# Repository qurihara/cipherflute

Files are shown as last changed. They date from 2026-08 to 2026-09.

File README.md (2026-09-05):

# CipherFlute



**3Dプリントした笛の音の高さに秘密を書き込み、吹いて読み出す。**

笛は電源も電子部品も持たない。家庭用の3Dプリンタで作れて、日用品の内部空洞として
存在できる。読み出しに特別な装置は不要である。

このリポジトリは、CipherFluteプロジェクトの成果物である。
開発は別のリポジトリで行っており、ここへはスクリプトで切り出している。

| | | |
|---|---|---|
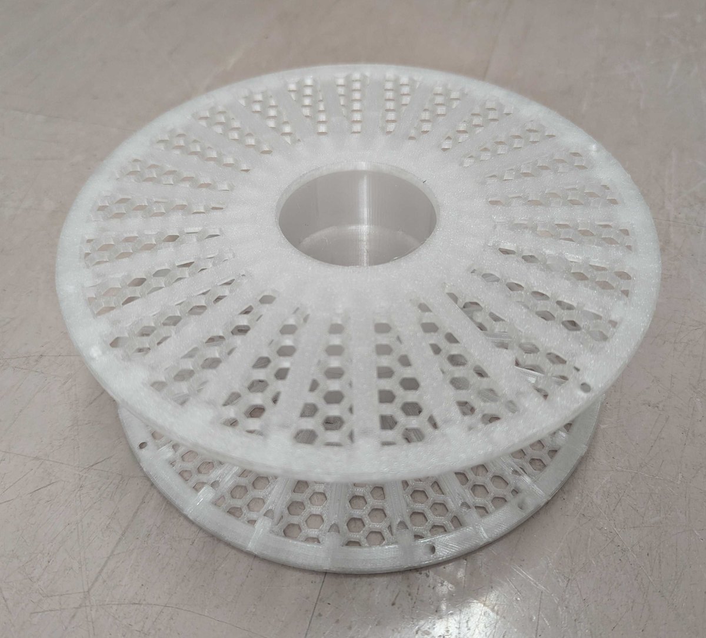
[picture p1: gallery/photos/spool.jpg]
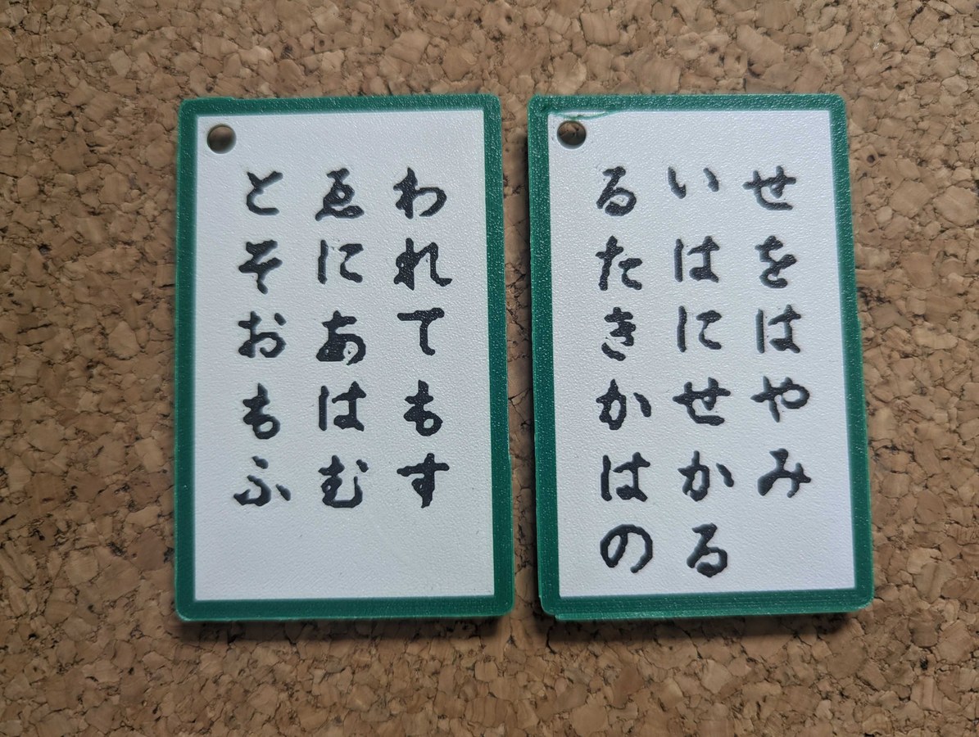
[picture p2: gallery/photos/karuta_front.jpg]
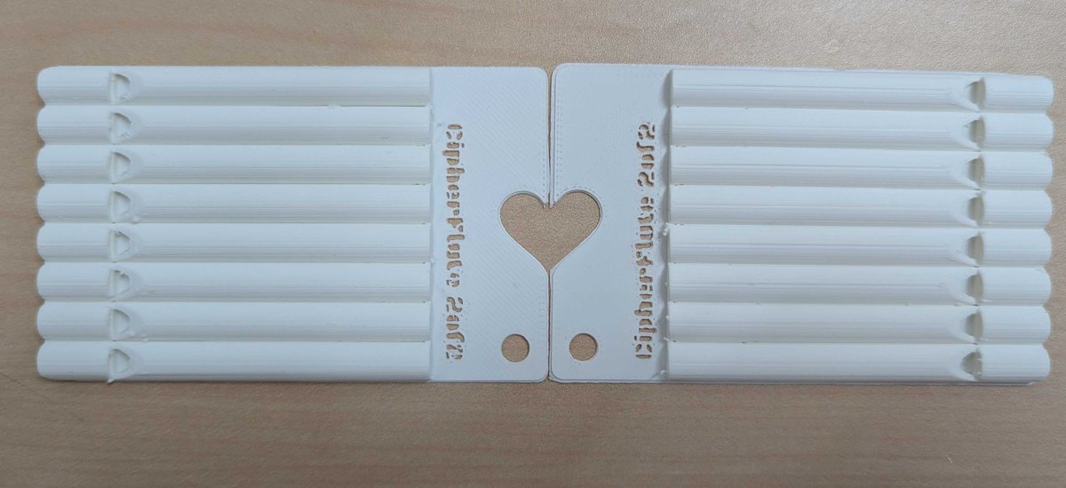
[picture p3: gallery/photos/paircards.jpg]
|  |  |  |
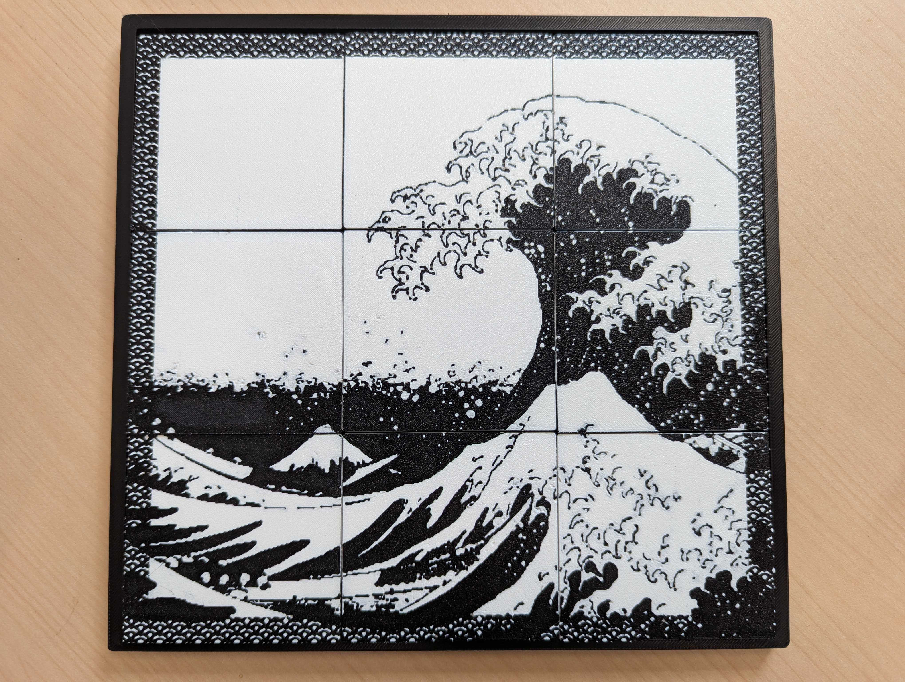
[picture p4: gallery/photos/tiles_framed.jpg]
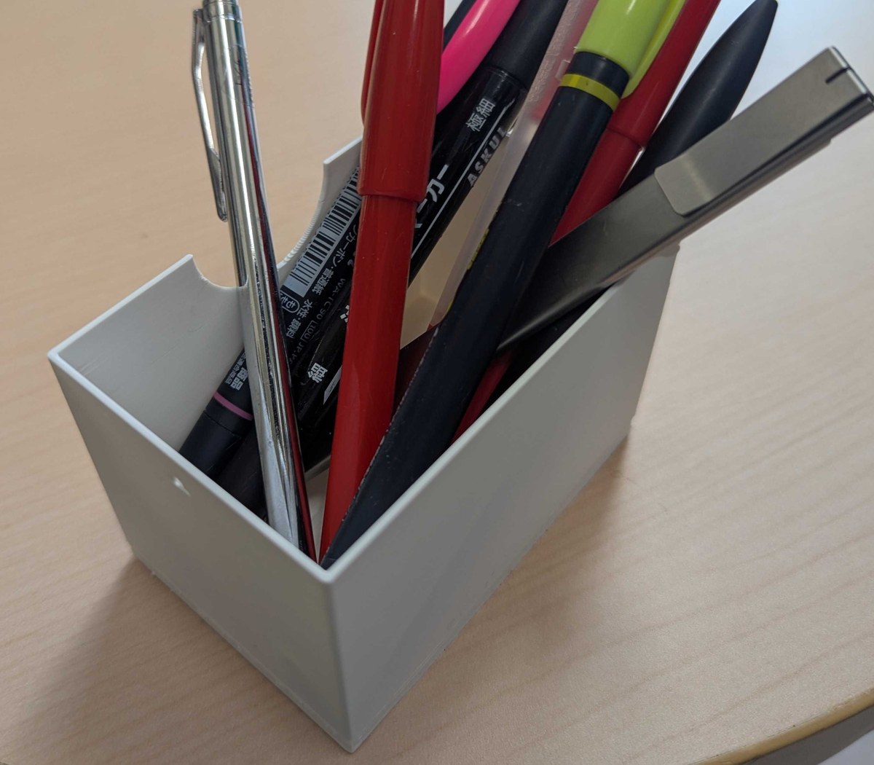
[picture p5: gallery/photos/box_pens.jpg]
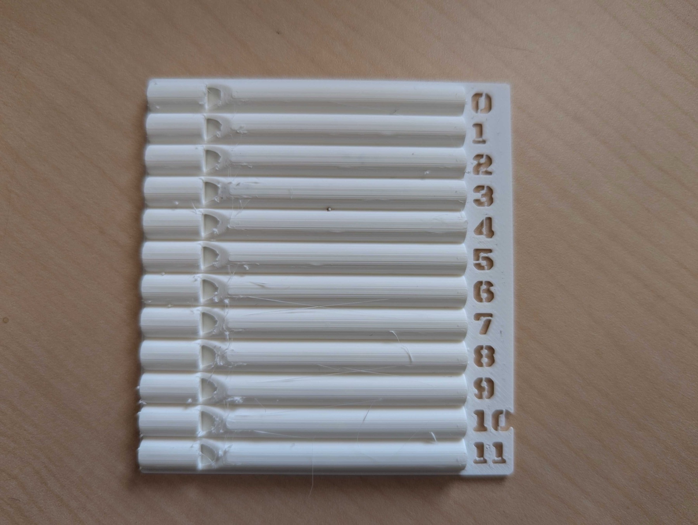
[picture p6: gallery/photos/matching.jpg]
|  |  |  |

写真の作例はどれも実機で復号まで通っている。詳しくは [`gallery/`](gallery/) を見ること。

## 5分で試す

1. `flutes/uniform/` の笛を何本か印刷する（0.20mm・サポートなし・ブリム8mm前後）
2. `decoder/index.html` をブラウザで開く
3. 「開始」を押して、印刷した笛を順に吹く

音の高さが読み取れれば、その並びが記号になる。何を書き込むかは、どの笛を
どの順で並べるかで決める。

## 中身

| 場所 | 何が入っているか |
|---|---|
| `flutes/` | 統一管長の笛12音ぶんのSTLと較正データ |
| `codec/` | 符号の参照実装（Python）と**試験ベクタ**と仕様書、**紙の上で復号するための早見表** |
| `decoder/` | ブラウザだけで動く復号器。検査94件つき |
| `embed/` | 日用品へ埋め込む道具と、2つの検査、**手順書2種** |
| `wallet/` | 笛から鍵と口座を導き、送金までできるページ（**テストネットの実験**） |
| `gallery/` | 作例の写真と造形データ（かるた札ペアキーホルダー・ペアカード・カード・箱・画像タイル・照合笛） |

## 笛の素材（`flutes/`）

スロット（音の高さの置き場）は **G#6 から G7 までの12個**、半音刻みである。半音刻みにしてあるので、
平均律の鍵盤楽器がそのまま対照表になる。

**外形はすべて同じ 65.97 × 7 × 4mm で、中の空洞の長さだけが違う。**
見ただけでは、どの笛がどの音かは分からない。

管の長さと音の高さは `calibration.json` の式で対応づける。

```
freq_hz = A / (bore_mm - e)      A = 87985.1, e = -10.010
```

**この係数は手元の環境で当てはめたものである。** プリンタや材料が違えばずれるので、
較正コームを刷って測り直すこと。当てはめには設計値ではなく、造形データから実測した
空洞の長さを用いている。

印刷して**鳴る向き**には範囲がある。横置きで、窓の向きが −135度から +135度の間なら
鳴る（360度のうち270度）。`embed/orient_check.py` で確認できる。

## 符号（`codec/`）

**同じ仕様を2つの言語で書いてある。** `codec/cipher_codec.py`（Python）と
`decoder/cipher_codec.js`（JavaScript）である。両者が一致していることを
`test_vectors.json` の12件で突き合わせている。

**別の言語で実装するときは、この試験ベクタで自分の実装を確かめられる。**

```bash
node decoder/cipher_codec.test.js     # ALL PASS (12 vectors)
```

符号の詳しい仕様は [`codec/SPEC.md`](codec/SPEC.md) にある。実装に足る細かさで記述してある。

**紙と鉛筆だけで誤り訂正まで行うための早見表**を [`codec/manual_decode_card.md`](codec/manual_decode_card.md)
に置いた。位数11の有限体では2が原始根なので、10項のべき乗表と10項の対数表があれば、
掛け算と割り算は足し算と引き算になる。手順が実装と食い違っていないかは
`codec/verify_manual_decode.py` で確認できる。

## 復号器（`decoder/`）

ブラウザだけで動く。その場で吹いても、録音した音声を入力しても復号できる。

読み取りの入口は4つある。

- 1本ずつ確定する
- 続けて吹いて、無音で自動送りする
- **一定のテンポで吹いて、あとからまとめて読む**（おすすめ）
- 録音ファイルを読み込む

音の高さは**笛の音域の中でいちばん強い山を追う**方式で検出する（`fft_peak.js`）。
自己相関にもとづく方式は、符号の最低音 G#6 に無関係な値を返すことがあり、使えない。

鳴らない笛があっても、拍を1つ空けて吹き続ければ、あとから拍を手がかりに
「飛ばし」を入れる。誤り訂正の消失として扱われるので、検査用の笛が足りていれば復元できる。

```bash
cd decoder && for t in fft_peak silence_segmenter tempo_filter cipher_codec; do
  node $t.test.js; done
```

## 日用品への埋め込み（`embed/`）

任意の3Dモデルに笛を配置して、印刷できる形にする。手順書は2つある。
人が読むなら [`embed/HOWTO.md`](embed/HOWTO.md)、
**大規模言語モデルの助手に読ませるなら** [`embed/flute-embed.md`](embed/flute-embed.md) である。
判断を伴う部分は手順書の側にあるので、埋め込みの再現には手順書とプログラムの両方を必要とする。

**核心は、笛の外形の凸包でホスト側にポケットを彫り抜いてから笛を戻すことである。**
これを略すと、ホストの材料が笛の空洞を埋めて鳴らなくなる。

作ったものが鳴るかどうかは、印刷する前に2つの検査で確認できる。

- `orient_check.py` … 印刷の向きが鳴る範囲に入っているか
- `check_cavity.py` … スライスした後の実際の経路を読み、空洞に材料が置かれていないか

**鳴らない物を作ってしまう失敗は、この2つでほとんど防げる。**

## 暗号笛ウォレット（`wallet/`）

笛を吹くと、その場で秘密鍵が組み立てられ、ブロックチェーン上の口座が現れる。
残高を見て、送金までできる。財布アプリは介さず、**笛から導いた鍵が直接署名する**。
鍵はどこにも保存せず、ページを閉じれば消える。

**★本物の資産には使わないこと。★** ネットワークはテストネット（Polygon Amoy）である。
カード1枚の秘密は20.8bitしかないので、**そこから導いた口座のアドレスが公開の台帳に
現れた時点で、総当たりで秘密鍵に到達される**。遅い鍵導出（PBKDF2 60万回）を通しても、
それは1候補あたりの費用を上げるだけで、足りない情報量を補うものではない。

対処は2つある。**128bitの秘密（スプール2枚）を使う**か、**笛の秘密に持ち主が覚えている
合言葉を混ぜて2要素にする**かである。後者はページで試せる（合言葉の既定は `demo`）。
詳しい検討は [`wallet/DESIGN.md`](wallet/DESIGN.md) にある。

```bash
node wallet/flute_key.test.js     # 鍵導出（9件）
node wallet/tx.test.js            # 送金（29件）
```

## 印刷の設定について

**同梱していない。** 機種と個体と材料に強く依存し、そのまま使うとかえって失敗するためである。
条件だけ記す。

- 層の厚さ 0.20mm（初層も同じ）
- サポート なし（笛は横置きで、ボアにサポートが入らない向きに置く）
- ブリム 外周のみ 8mm 前後（薄く面積の大きい板では反り止めに効く）
- 材料 PLA。PETGでも鳴るが、薄い壁では失敗しやすい

## 何が守られ、何が守られないか

**方式そのものは公開であり、秘密は値だけである。**

- 物体の層にも音の層にも、暗号学的な秘匿の力は**無い**
- 音は公開のチャネルである。吹いているところを録音されれば秘密は漏れる
- 形状が秘密である。3Dスキャンや写真測量で読まれうる
- 秘匿が必要なら**秘密分散**を使う。`codec/threshold.py` にShamirの実装がある

## ライセンス

- コード … MIT（[LICENSE](LICENSE)）
- 3Dデータ・写真 … CC BY 4.0（[LICENSE-assets](LICENSE-assets)）
- 第三者の権利については [NOTICE.md](NOTICE.md) を読むこと

## 引用

```bibtex
@misc{cipherflute,
  author       = {栗原 一貴},
  title        = {CipherFlute},
  year         = {2026},
  howpublished = {\url{https://github.com/qurihara/cipherflute}}
}
```

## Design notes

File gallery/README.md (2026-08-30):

# 作例

実機で復号まで通ったものである。造形データは、どれもデモ用の秘密を記録してある。

| 作例 | 秘密の分け方 | 笛の本数 | 造形データ |
|---|---|---|---|
| かるた札ペアキーホルダー2枚 | 2-of-2 | 8本ずつ | `models/karuta_2of2.3mf` |
| ハートを抜いたペアカード | 2-of-2 | 8本ずつ | `models/paircards_2of2.3mf` |
| カード1枚 | 単体、または2-of-3の断片 | 8本 | `models/card.3mf` |
| 箱 | 2-of-3の断片 | 8本 | `models/box.3mf` |
| 画像タイル9枚 | 2-of-9 | 9本ずつ | 額縁と脚のみ同梱 |
| 照合笛 | なし（読み出しの道具） | 12本 | `models/matching.3mf` |

## かるた札ペアキーホルダー2枚

百人一首の1首を上の句と下の句に分けて刷り、それぞれの裏に笛を8本ずつ載せた。
崇徳院の「瀬をはやみ岩にせかるる滝川のわれても末に逢はむとぞ思ふ」を選んである。

**分かれてもいずれまた出会うという歌の内容が、2-of-2の秘密分散そのものになっている。**
2枚をそろえる理由が物の側に書いてあり、歌の完成と秘密の復元が一致する。

- クレジットカードと同じ寸法を縦長にとり、厚さ4.8mm。絵柄0.4mm＋素地0.4mm＋笛4mm
- 白い地に黒い字を刷り、縁を緑で囲んだ3色刷りである
- 絵柄は0.4mmの格子に量子化されるので、1文字を29画素にとって毛筆の入りと払いを残した
- **2枚の札は先頭の2本が同じ音である。**基準笛と、差分の写像で決まる次の1本が
  両方に共通するためで、**吹く向きを間違えていないかは、1本目が基準笛の高さになるかで分かる**

| 写真 | 何が写っているか |
|---|---|
| `photos/karuta_front.jpg` | 2枚を並べたところ。右が上の句、左が下の句 |
| `photos/karuta_back.jpg` | 上の句の札を裏返したところ。笛8本が並ぶ |

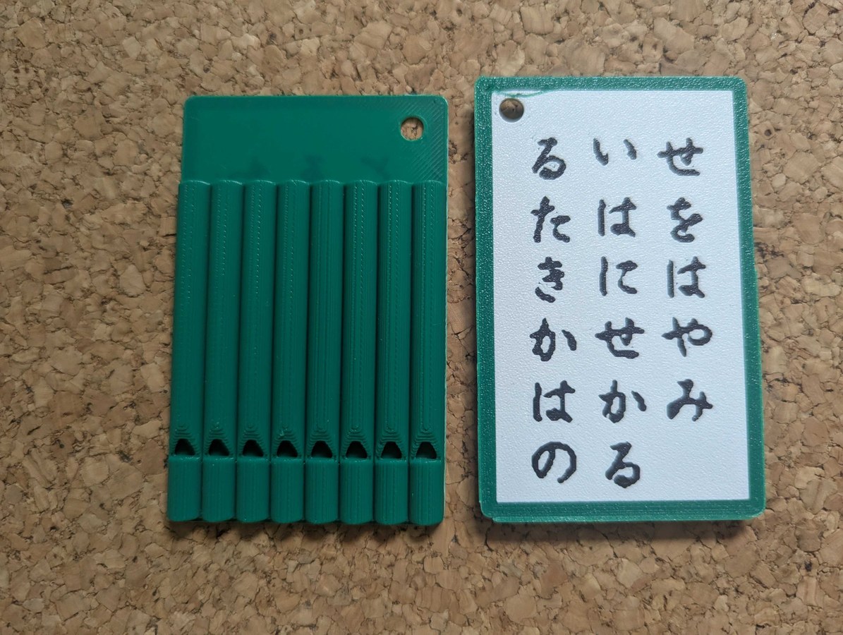
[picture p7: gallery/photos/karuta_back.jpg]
 

## ハートを抜いたペアカード

同じ作りのカードを2枚、余白どうしを向かい合わせに並べ、その境界にハートを抜いた。
1枚では半分のハートにしかならず、**2枚をそろえて初めてハートが現れる。**

秘密は2-of-2で分け、片方に一方の値を、もう片方に秘密からその値を引いた値を割り当てる。
方式としては、片方だけでは一様な乱数にしか見えない。
**ただしこのリポジトリの実装は、再現できるように分け方の値を固定してある。**
実際に配る物を作るときは、組ごとに種を変えること。

合成した秘密を鍵として遷移先のURLを暗号化しておくと、2枚がそろったときにだけそのページが開く。
この秘匿の強度は、載っている情報量（20.8bit）のままである。

| 写真 | 何が写っているか |
|---|---|
| `photos/paircards.jpg` | 2枚をそろえてハートが現れたところ |



## カード1枚

クレジットカード大の板（85.6 × 54 × 4mm）に笛8本を融合したものである。
先頭の1本を基準笛にあて、残り7本にデータとパリティの記号を載せる。**20.8bitを記録する。**

財布に入れて持ち歩ける薄さで、見た目は音楽用のカードと同じである。

| 写真 | 何が写っているか |
|---|---|
| `photos/card.jpg` | カード1枚。右上の印が吹き始めである |
| `photos/card_2of3.jpg` | 2-of-3の断片を担当するカード |

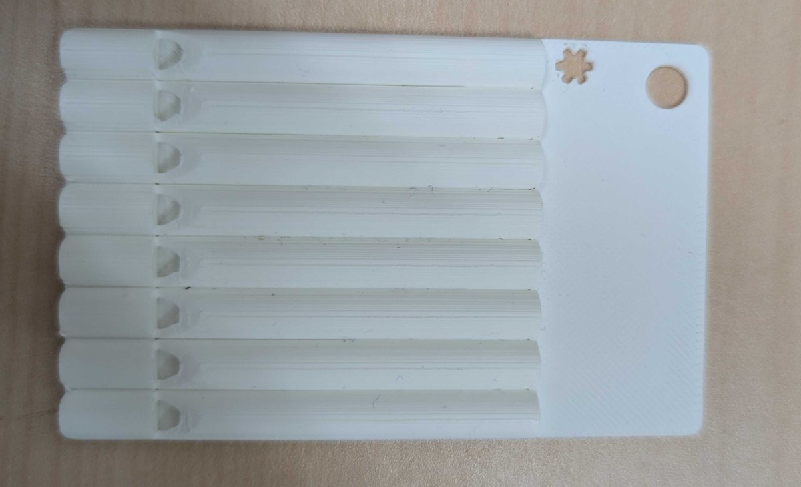
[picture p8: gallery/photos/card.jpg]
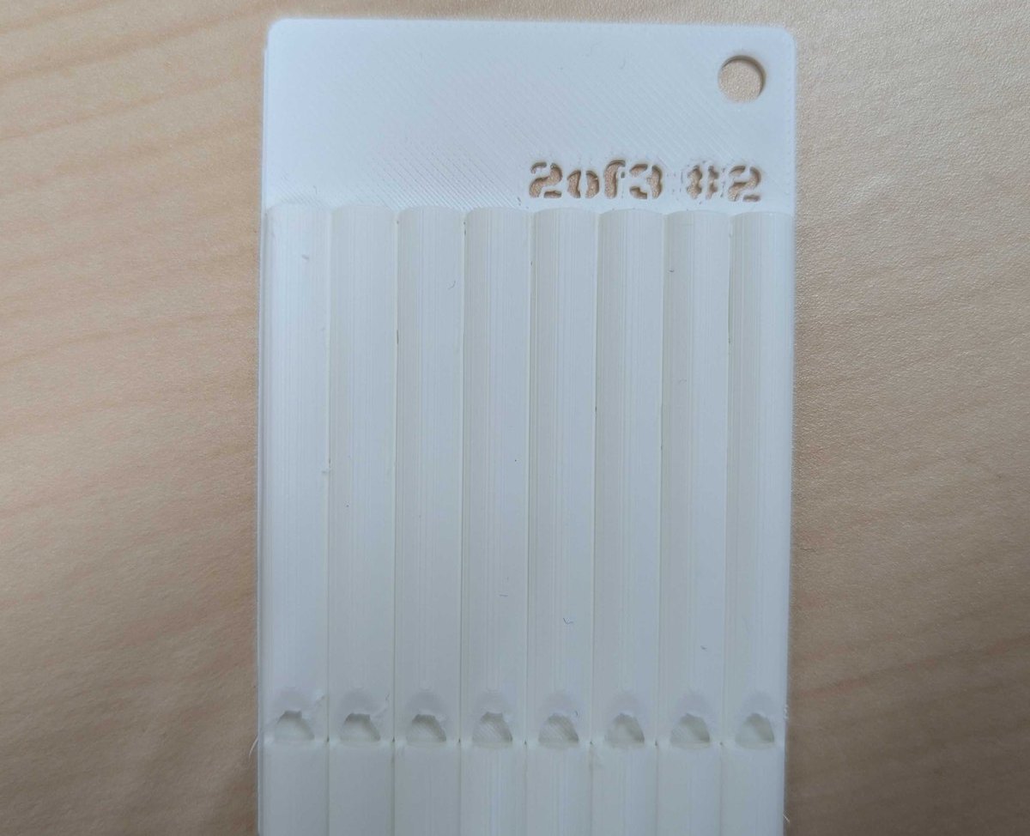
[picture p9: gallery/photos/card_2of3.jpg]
 

## 箱

箱の床に笛を埋め込んだものである。

ペンを立てれば、机の上では文房具に見える。

| 写真 | 何が写っているか |
|---|---|
| `photos/box_inside.jpg` | 箱の内部。床に笛を埋め込んである |
| `photos/box_pens.jpg` | ペンを立てたところ |

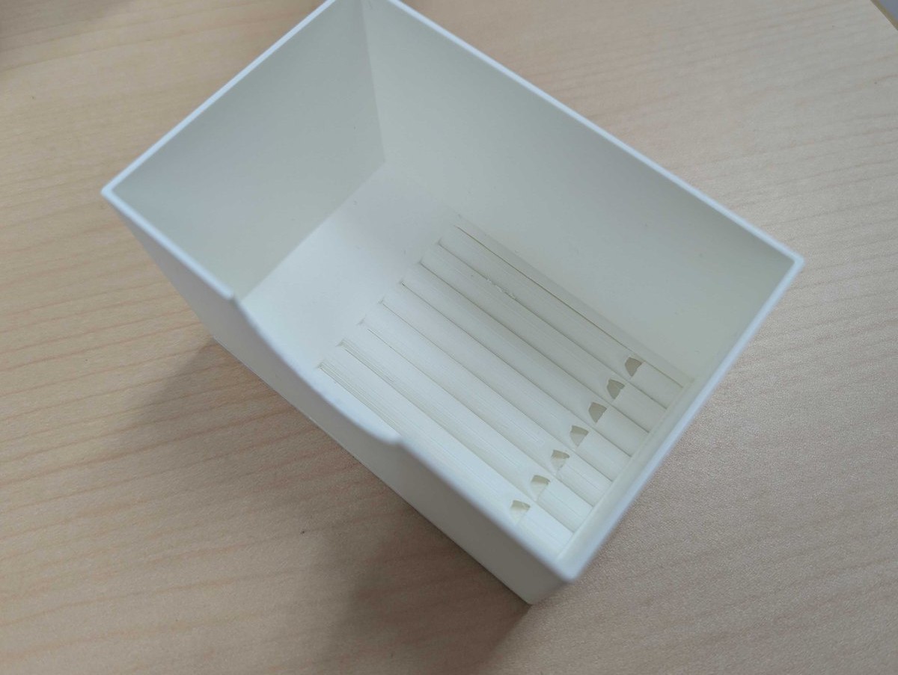
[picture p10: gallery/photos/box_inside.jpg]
 

カードと箱は、形の違う日用品で2-of-3の秘密分散を分担する組の一部である。

## 暗号笛内蔵画像タイル

絵を格子に割って9枚のタイルにし、それぞれの裏に笛を9本ずつ、合わせて81本を載せた。

**並べ直すと絵が戻り、裏返して吹くと秘密が戻る。**

- 秘密の分け方は 2-of-9。**9枚のうちどの2枚がそろっても復元できる**
- タイルは 68.0 × 64.6 × 4.78mm。絵柄0.4mm＋素地0.4mm＋笛4mm
- 額縁（`models/frame_box.stl`・外寸 214.5 × 204.4 × 6.7mm）に収まる
- 脚（`models/frame_stand.stl`）を背面に貼ると、12度傾いて自立する

| 写真 | 何が写っているか |
|---|---|
| `photos/tiles_framed.jpg` | 9枚を額縁に収めたところ |
| `photos/tiles_back.jpg` | **1枚を裏返したところ。笛9本が並ぶ** |
| `photos/tiles_standing.jpg` | 脚を付けて自立させたところ |

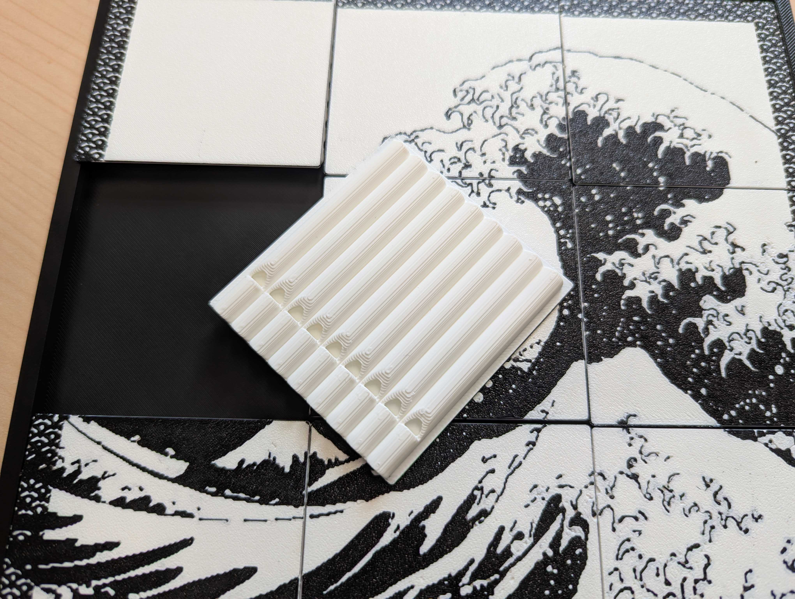
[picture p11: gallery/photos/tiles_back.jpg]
 
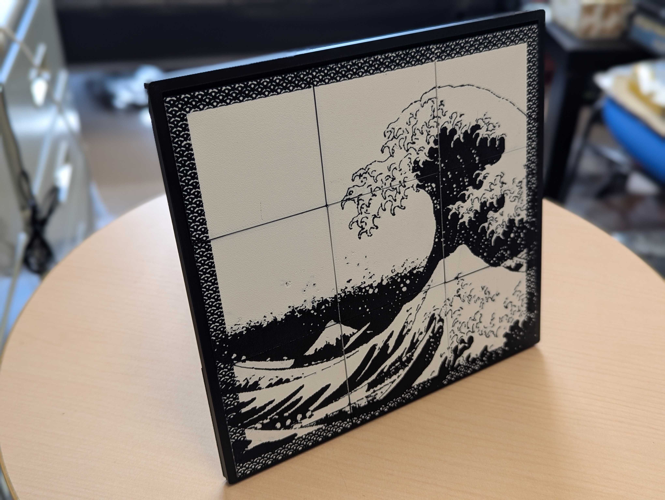
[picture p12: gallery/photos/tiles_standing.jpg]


**絵柄を下向きに刷る板は、刷る段階で左右を返しておくこと。** 見るときに裏返すので、
返さないと鑑賞時に鏡像になる。写真の作例は、これに気づく前に刷ったものなので鏡像である。

## 照合笛

12個のスロットに対応する笛を、1枚の板に1本ずつ並べた、読み出し用の物差しである。
データの笛と聞き比べ、同じ高さで発音する笛を探す。**うなりが消えたところに刻んである
番号が、そのスロットの記号である。** 電子機器を持たない読み出しは、この板で完結する。

- **すべての笛が同じ外形である。** 長さから音高を当てられないので、読み手は刻んだ番号で見分ける。データの笛と造形の条件もそろう
- 番号0〜11は各笛の足の先に、板だけを貫通する抜き文字として刻んである。番号そのものが順序と向きを示す
- 秘密を載せていないので、この造形データは共有できる。データの笛と同じプリンタ・同じ材料で刷ると、個体差が共通になって聞き比べやすい

| 写真 | 何が写っているか |
|---|---|
| `photos/matching.jpg` | 照合笛。12スロットの笛を1枚の板に並べ、番号を刻んである |



## そのほかの作例（写真のみ）

論文と動画に登場する作例のうち、造形データを未収録のものである。

| 作例 | 何であるか |
|---|---|
| `photos/spool.jpg` | フィラメントのスプール。円盤2枚に笛49本で128bitを記録する |
| `photos/bookstand.jpg` | 本立て。底板に笛36本で64bitを記録する |

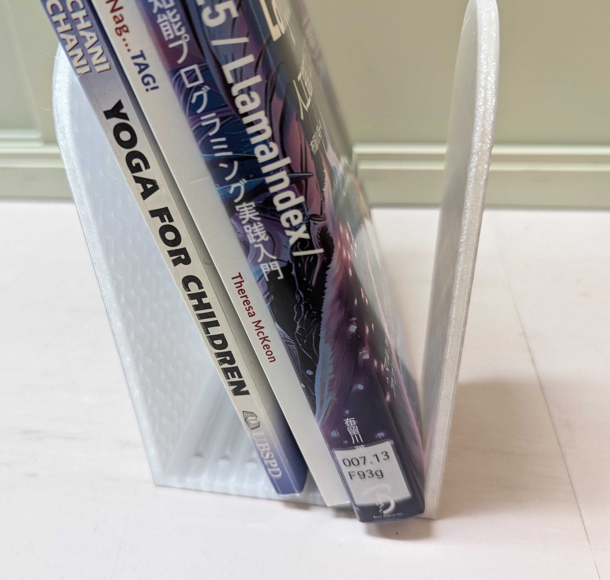
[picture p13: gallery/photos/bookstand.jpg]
 

## 権利について

[../NOTICE.md](../NOTICE.md) を読むこと。

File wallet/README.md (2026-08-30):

# 暗号笛ウォレット（段階0）

笛を吹くと、その場で秘密鍵が組み立てられ、Polygon Amoy 上の口座が現れる。鍵はどこにも保存しない。
契約は使わない（段階0）。設計の検討は [DESIGN.md](DESIGN.md) にある。

## 中身

| ファイル | 役割 |
|---|---|
| `index.html` | 画面。笛を吹く→鍵を作る→アドレスと残高を出す→送る |
| `flute_key.js` | 秘密から口座を作る。PBKDF2（60万回）→ secp256k1 → keccak |
| `flute_key.test.js` | 鍵導出の検査。`node docs/dapp/flute_key.test.js`（9件） |
| `tx.js` | 取引を組み立てて署名する。RLP・EIP-1559・secp256k1 |
| `tx.test.js` | 送金の検査。`node docs/dapp/tx.test.js`（29件） |
| `vendor/` | 外部ライブラリの実体。CDNから読まず、ここに置いたものだけを使う |

## 鍵の作り方（仕様）

```
入力 = 秘密のバイト列                        （合言葉が空のとき）
入力 = 秘密のバイト列 ‖ 0x1f ‖ 合言葉         （合言葉があるとき）
salt = "cipherflute/v1" + "|" + ラベル        （例 "cipherflute/v1|amoy"）
seed = PBKDF2-HMAC-SHA256(入力, salt, 600000回, 32バイト)
秘密鍵 = seed（曲線の外に出たら salt に通し番号を足して作り直す）
アドレス = keccak256(公開鍵の非圧縮65バイトの先頭1バイトを除いた部分) の下位20バイト
```

**合言葉は秘密の側に混ぜる**（saltではなく）。saltは公開してよいものとして扱っており、
合言葉は秘密の一部だからである。区切りに 0x1f を入れるのは境目を曖昧にしないためで、
これが無いと 秘密"26"＋合言葉"0812" と 秘密"260"＋合言葉"812" が同じ入力になってしまう。
**合言葉が空のときは何も足さない**ので、これまでに作った口座は変わらない。

**この仕様を変えると、既に印刷した笛が別の口座を指す**。版（`cipherflute/v1`）と繰り返し回数は
仕様の一部であり、迂闊に変えてはいけない。検査（`flute_key.test.js`）がその見張りである。

## 手元で動かす

```
python3 -m http.server 8765 --directory docs
```
のあと `http://localhost:8765/dapp/` を開く。ES モジュールを使うので `file://` では動かない。

## ★読む笛の設定はURLで決める★

読む笛の設定は、一覧からの選択ではなくURLで受け取る。**物が増えても選択肢が増えず、
第三者も自分の笛の設定を持ち込める。** 復号ページ（`docs/cipher/`）と同じパラメータの
書き方であり、台帳に載せているURLの `#` から後ろをそのまま貼れば読める。

```
?lo=G%236&hi=G7&norepeat=1&mode=symbols&parity=1&cards=2&expect=8&name=かるた2枚
```

| 名前 | 何を決めるか |
|---|---|
| `lo` `hi` | 音域（`#` は `%23` と書く） |
| `parity` | パリティ記号の数 |
| `mode` | `symbols`（記号）か `sequential`（バイト列） |
| `norepeat` | 隣接同音の禁止。既定は有効、`0` で無効 |
| `cards` | 何枚吹くか。既定は2 |
| `expect` | 1枚あたりの本数。既定は8 |
| `name` | 画面に出す名前 |
| `label` | 口座のラベル。変えると同じ笛から別の口座になる |
| `ref` `step` `useref` | 基準笛・刻み・基準笛を使うか |

検索の側（`?`）と断片の側（`#`）のどちらでも受ける。断片で書くと設定がサーバの記録に残らない。

**★設定が違っても読めてしまうことがある★** その場合は黙って別の口座が開く。たとえば
パリティ2の札をパリティ1で読むと、エラーにならないまま違う値になる（実際に2-of-3の
カードで起きる）。読み終えたら、画面に出る記号が台帳の値と合っているかを確かめるとよい。

**どの物も単体で何かの口座に紐づく。** 2-of-2 の1枚、2-of-3 の断片1つ、2-of-9 のタイル1枚は、
それぞれ独立した口座を持つ。そこから合成後の秘密は辿れない（鍵導出は一方向）。
ただし**その口座のアドレスが台帳に現れると、総当たりで断片の値が求まる**ので、
秘密分散の余裕はその分だけ減る。デモではデモ用の秘密しか使わないので構わないが、
実運用では合言葉を秘密のものにするか、128bitの秘密を使うこと。

## 接続先（RPC）

Polygon Amoy（chainId 80002）は稼働している。ただし**Polygon公式の `rpc-amoy.polygon.technology` は
場所によって届かない**。2026-08-17に確かめたところ、次の2つは届いた。

| 接続先 | 2026-08-17 |
|---|---|
| `https://polygon-amoy-bor-rpc.publicnode.com`（既定） | 届く |
| `https://polygon-amoy.drpc.org` | 届く |
| `https://rpc-amoy.polygon.technology` | 届かない |

画面の接続先の欄は選べるようにしてあるので、繋がらないときは別のものを選ぶ。

テスト用トークンの蛇口は、**Polygon公式のものは終了した**。Alchemy（24時間ごとに0.1 POL）か
QuickNode を使う。どちらも登録を必要とする。

## いまできること・まだできないこと

* できる … 笛を吹いて口座を開く、アドレスを見る、残高を確認する、**送金する**
* まだ … 契約を使う段階（2枚そろって初めて開く金庫、時限や相続）。[DESIGN.md](DESIGN.md) の段階1と段階2

## 送金の作り

`tx.js` が担当する。EIP-1559（type 2）の取引を組み立て、RLPで符号化し、keccak256でハッシュし、
笛から導いた鍵で署名して `eth_sendRawTransaction` で送る。財布アプリは介さない。

**押しただけでは送らない。** 先に「内容を確かめる」で、送り主・宛先・金額・手数料の上限・
合わせて要る額・通し番号・チェーンを画面に出す。人が読んでから署名する。

検査は `node docs/dapp/tx.test.js`（29件）。RLPを公式の例で照合し、**署名から署名者の
アドレスが復元できること**を検証している。ここが1バイト狂うと、署名は通るのにチェーンが
受け取らない、あるいは別の内容の取引として通ってしまう。

手数料は、そのときの基準手数料が2倍に上がっても通る上限を取る。使われなかった分は返る。
Amoyは優先手数料に最低25 gwei前後を要求するので、下限を置いてある。

## ★これは実験である★

**本物の資産には使わない。** カード1枚の秘密は20.8bitしかないので、そこから導いた口座の
アドレスが公開の台帳に載った瞬間、**総当たりで秘密鍵に到達される**。テストネットのトークンには
金銭価値が無いので損害は出ないが、同じ作りを本番のチェーンで使ってはならない。
価値のあるものを預けるなら、128bitの秘密（スプール2枚）を使うか、笛の秘密と利用者が覚えている
合言葉を混ぜて2要素にする。詳しくは [DESIGN.md](DESIGN.md) の2.2を読むこと。

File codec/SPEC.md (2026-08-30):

# 符号の仕様

**別の言語で実装する人のための記述である。** 論文の設計章は読み物として書いてあるので、
ここでは実装に必要なことだけを、順を追って記述する。

参照実装は2つある。`cipher_codec.py`（Python）と `../decoder/cipher_codec.js`（JavaScript）で、
どちらも同じ仕様を実装している。**書いたら `test_vectors.json` で突き合わせること。**

## 1. 音の高さの置き場（スロット）

音の高さを離散化した置き場を**スロット**と呼ぶ。

- 範囲は `lo_note` から `hi_note` まで。既定は **G#6 から G7** の12個
- 刻みは `step_cents`。既定は **100セント（半音）**
- 半音刻みにしてあるので、平均律の鍵盤楽器がそのまま対照表になる

スロット `i` の周波数は、`lo_note` の周波数に `i × step_cents` を足したものである。

```
freq(i) = freq(lo_note) × 2^(i × step_cents / 1200)
```

## 2. 基準笛

先頭に1本、**基準笛**を配置する。既定は **C7** である。

読み出しでは、まず基準笛の実測周波数を取り、以降のすべての音を**基準笛との比**で読み取る。
これにより、気温による伸縮も、吹く強さのくせも、まとめて打ち消せる。絶対音感も、
楽器が特定の調律であることも不要である。

```
残差(i) = 1200 × log2( (実測 / 基準の実測) / (スロットiの公称 / 基準の公称) )
```

残差が最も小さいスロットを選ぶ。残差が `decision_guard_cents`（既定は `step_cents / 2`）
を超えていれば、**読めなかった**として消失の印を付ける。

**基準笛はデータの音域の外に置いてもよい。** `use_reference=false` にすると基準笛を使わず、
絶対音程で読む（温度補正が効かなくなる）。

## 3. 隣接同音の禁止と差分符号化

`no_repeat=true` のとき、**隣り合う笛が同じ音にならない**ように符号化する。

理由は読み出しにある。同じ音が続くと、1本なのか2本なのかを音だけでは区別できない。
無音で区切る読み方でも、息が続いてしまえば同じことである。

実装は差分符号化による。記号 `d`（0 以上 `m-1` 未満、`m` はスロット数から1引いた数）を、
1つ前のスロット番号から `d + 1` だけ進んだ位置として書く。

```
slot[k] = (slot[k-1] + d[k] + 1) mod スロット数
```

起点は基準笛の公称スロットである。これにより、隣り合う笛は必ず違うスロットになる。

**1本あたりの情報量は log2(スロット数 − 1)。** 12スロットなら **log2(11) = 3.459 bit**。
隣接同音を禁じても、12スロットなら情報量は実質保たれる。

## 4. 誤り訂正

Reed-Solomon 符号を使う。有限体の位数 `p` はスロット数から決まる素数である
（12スロットなら `m = 11`、位数11）。

- `ecc_parity` … 1ブロックあたりの検査記号の数。既定 **2**
- ブロックの長さは、記号の総数から自動で決める（`_block_layout`）
- **消失（どこが読めなかったか分かっている誤り）は、検査記号の数だけ訂正できる。**
  値の誤り（位置が分からない）は、その半分

読めなかった笛は**位置を詰めてはいけない**。詰めると以降の記号がすべてずれ、
本来なら直せる1本の欠落すら直せなくなる。**位置を保ったまま消失として渡す。**

## 5. 記録するもの（mode）

- `mode="sequential"` … バイト列を記録する。`payload` が `bytes`
- `mode="symbols"` … 記号の列をそのまま記録する。小さな秘密や、人が判読する番号に向く

## 6. 読み出しの手順（まとめ）

1. 音を1本ずつに切り分ける
2. 先頭を基準笛として、その実測周波数を取る
3. 以降の音を基準との比でスロットに丸める。丸められないものは消失にする
4. 差分符号化を解く（`no_repeat` のとき）
5. Reed-Solomon で訂正する
6. `mode` に応じてバイト列か記号列を取り出す

## 7. 秘密分散との組み合わせ

`threshold.py` に Shamir の秘密分散がある。k-of-n の断片を作り、各断片を1つの物体に格納する。

**実装上の注意。最高次の係数を 0 にしてはいけない。** k=2 で係数が0だと多項式が定数になり、
**すべての断片が秘密そのものになる**。`randrange(1, p)` を使うこと。

秘密分散を実装したら、**断片を並べて「全部同じ値の記号が無いか」を必ず見ること。**
この検査で係数0の事故に気づける。

## 8. 試験ベクタ

`test_vectors.json` に12件ある。構造は次のとおり。

```json
{
  "config": { ... 符号の設定 ... },
  "vectors": [ { "payload": "...", "notes": ["C7", "G#6", ...] }, ... ]
}
```

各ベクタについて、`payload` を符号化すると `notes` になり、`notes` を復号すると
`payload` に戻ることを確かめる。

```bash
node ../decoder/cipher_codec.test.js     # ALL PASS (12 vectors)
python3 -c "import cipher_codec; print(cipher_codec.selftest())"
```

## 9. この仕様が守らないこと

**暗号学的な秘匿は一切無い。** 方式は公開で、秘密は値だけである。

- 音は公開のチャネルである。録音されれば読まれる
- 形状が秘密なので、3Dスキャンや写真測量で読まれうる
- 検査記号は事故（吹き損じ）を見つけるためのもので、**偽造を防ぐものではない**。
  仕様を知る者は、整合する偽物を作れる

秘匿が必要なら、秘密分散に一元化すること。復元した秘密そのものが自己検証的であること
（ハッシュが一致する、署名鍵として機能する）で、真正性を上の層に持たせる。

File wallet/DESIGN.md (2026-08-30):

# 暗号笛 dApp（Polygon Amoy）設計メモ

2026-07-29 起案。笛から復号した秘密を、そのままブロックチェーン上の鍵として使う仕組みの検討。
サーバを持たず、ブラウザだけで完結させることを前提にする。

---

## 1. 何を作るか（3段階）

段階を分けて考えると、どこまでが契約なしで成り立ち、どこから契約が要るのかがはっきりする。

### 段階0：笛そのものが口座になる（契約は不要）

笛の秘密から決まった手順で秘密鍵を作り、そのアドレスを口座として使う。ブラウザで笛を吹くと
鍵が手元に戻り、その場で送金に署名できる。**ブロックチェーンには何も特別なものを載せない**。
ふつうの外部所有アカウント（EOA）が1つあるだけである。

これが「暗号笛＝ハードウェアウォレット」の最小の形であり、いちばん強い主張になる。契約を
書かなくても成立する点が重要で、**契約の欠陥という攻撃面をそもそも持たない**。

### 段階1：2枚そろって初めて動く金庫（契約が要る）

カード2枚の 2-of-2 を、そのままチェーン上の 2-of-2 に対応させる。金庫の契約が資産を預かり、
**2枚から復元した秘密で作った鍵の署名**があるときだけ引き出せる。物の形（半分のハートが2枚で
そろう）と、契約の条件（2つそろって初めて解ける）が一致する。

### 段階2：時間と相続（契約が要る）

「この日以降でなければ開かない」「一定期間だれも触らなければ、指定した相手が開けられる」と
いった条件を契約に書く。物理の笛は時間を知らないので、ここは契約でなければできない。
遺言やデジタル遺産の引き継ぎという用途に直結する。

---

## 2. セキュリティの検討

### 2.1 いちばん大事な制約：載せた瞬間に世界中へ公開され、消せない

ブロックチェーンは公開の台帳である。暗号文もハッシュも、書き込んだ瞬間に誰でも取得でき、
**あとから消せない**。したがって「秘密のハッシュを載せて照合する」という素直な設計は、
**秘密のエントロピーが小さいと、その場で破られる**。

### 2.2 担体ごとのエントロピーと、総当たりの現実性

| 担体 | エントロピー | 素のハッシュで総当たり | 遅い鍵導出（PBKDF2 60万回相当）で総当たり |
|---|---|---|---|
| カード1枚 | 20.8 bit | 一瞬 | 約1.5分 |
| カード2枚（2-of-2） | 20.8 bit | 一瞬 | 約1.5分 |
| 本立て | 64 bit | 約59年 | 実質不可能 |
| スプール2枚 | 128 bit | 実質不可能 | 実質不可能 |

（GPU 1台を 1e10回/秒、遅い鍵導出を 2e4回/秒と仮定した目安）

ここから導かれる結論は明快である。

* **価値のある資産を預けてよいのは、スプール（128 bit）だけ**である。本立て（64 bit）も
  遅い鍵導出と併用すれば当面は持ちこたえるが、余裕を見るなら128 bitを使う。
* **カード（20.8 bit）は、そのままでは公開台帳に載せてはいけない**。アドレスを1つ登録した
  時点で、総当たりで秘密鍵まで到達される。カードを使いたい場合は次のどちらかにする。
  1. デモに徹する（Amoyのテスト用トークンには金銭価値が無いので、破られても損害がない）。
  2. **2要素にする**。笛の秘密に、利用者が覚えている合言葉を混ぜて鍵を作る。合言葉が
     40 bit あれば合計60 bit級になり、総当たりは現実的でなくなる。

### 2.3 鍵の作り方

```
seed = KDF(secret_bytes, salt = "cipherflute/v1|" + object_id, iterations = 600,000)
privkey = seed（32バイト、secp256k1の範囲へ縮約）
address = keccak(pubkey)[12:]
```

* **遅い鍵導出を必ず通す**。素のハッシュだと、上表のとおり小さい秘密が即座に割れる。
  ブラウザ標準の WebCrypto に PBKDF2 があるので、追加の依存なしで書ける。より強くするなら
  Argon2id（WebAssembly）を使う。
* **salt に版と物の識別子を入れる**。同じ笛から常に同じ口座が出ること（決定性）と、
  別の物・別の用途で鍵が衝突しないことの両方を満たす。salt は公開してよい。
* **版を名前に入れる**。将来 KDF を変えたとき、古い笛の口座を失わないようにするため。

### 2.4 署名の横取り（front-running）

契約に「正しい署名を出した人へ払う」と書くと、送信された取引を見た第三者が**同じ署名を
コピーして手数料を上乗せし、先に取り込ませる**ことができる。ブロックに入る前の取引は
公開の待ち行列に並ぶためである。

対策は、**署名の中に受取人のアドレスを含める**ことである。EIP-712 の型付きデータとして

```
Claim(address vault, uint256 chainId, address claimer, uint256 nonce, uint256 deadline)
```

に署名すれば、他人がコピーしても claimer が自分ではないので使えない。nonce で再利用を防ぎ、
deadline で古い署名を無効にする。chainId と契約アドレスを含めることで、別のチェーンや
別の契約への使い回しも防げる。

### 2.5 ブラウザが信頼境界になる

笛の秘密も秘密鍵も、ブラウザのメモリ上に現れる。したがって次を守る。

* **静的ページを HTTPS で配る**（GitHub Pages でよい）。第三者のスクリプトを読み込まない。
  読み込むなら Subresource Integrity を付ける。
* 秘密鍵を localStorage に保存しない。ページを離れたら消える状態にする。
* 何に署名しようとしているのかを、必ず人間が読める形で画面に出す。
* 拡張機能による盗み見は防げない。金額の大きい用途では専用の端末を使うべきである、と明記する。

### 2.6 物理面のリスクは変わらない

笛は静的な形状なので、**保管場所を知られたら、吹かなくても計測や透過撮影で読める**。これは
論文の脅威モデルと同じで、チェーンを使っても変わらない。守るのは秘密分散と保管の分離である。

### 2.7 テストネットである意味

Amoy のトークンには金銭価値がない。したがって**設計の誤りが金銭の損失に直結しない**。
仕組みを見せる目的にはむしろ適している。本番のチェーンへ移すかどうかは、上の
エントロピーの条件（128 bit を使う、2要素にする）を満たしてから判断する。

---

## 3. ブロックチェーンに何を載せるか

### 載せてよいもの

* 笛から導いた口座の**アドレス**（公開鍵のハッシュ。ただし2.2の条件を満たす場合に限る）
* 金庫の**状態**（未開封・開封済み、開封した時刻、受取人）
* **開封の記録**（イベントログ）。「この時刻に、この物を吹いて開けた」という証跡が公開台帳に
  残ることは、相続や複数人での開封式では利点になる。
* 時限や条件などの**規則そのもの**
* 128 bit の秘密で暗号化した**小さな暗号文**（遷移先URLなど）。エントロピーが足りている
  ときに限る。

### 載せてはいけないもの

* **秘密そのもの**（言うまでもない）
* **小さい秘密のハッシュ**。載せた瞬間に総当たりで割られる。ハッシュは秘匿ではない。
* **笛の音の並びや写真、寸法**。これらは秘密そのものである。
* 個人を特定できる情報。公開台帳は消せない。

---

## 4. 技術スタックの検討

サーバを持たない前提で、次の構成を推す。

| 層 | 選択 | 理由 |
|---|---|---|
| 配布 | GitHub Pages（既存の docs/ をそのまま使う） | すでに復号ページを置いており、追加費用も運用も要らない |
| 音の復号 | 既存の `cipher_codec.js` と pitchy | 実機で動いている資産をそのまま使う |
| 鍵導出 | WebCrypto の PBKDF2（必要なら Argon2id の WebAssembly） | 追加依存なしで始められる |
| チェーン接続 | **viem**（または ethers v6） | 型が付き、ツリーシェイキングが効いて配布が軽い。Amoy を標準で持つ |
| 署名 | EIP-712 型付きデータ | 人が読める形で内容が出る。横取り対策の項目を型に入れられる |
| 財布 | MetaMask（手数料の支払い用）／または笛から導いた鍵で直接署名 | 段階0では財布すら要らない |
| 契約 | Solidity 0.8.x ＋ OpenZeppelin（ECDSA, EIP712） | 実績のある実装を使い、自作の暗号処理を書かない |
| 開発 | Foundry（`forge test`, `forge script`） | テストが速く、鍵の扱いを含めた検証を書きやすい |
| ネットワーク | Polygon Amoy（chainId 80002） | 指定どおり。RPC は公開のもので足りる |

手数料の支払いだけは、どうしても資金のある口座が要る。選択肢は2つある。

1. **利用者の MetaMask で払う**。笛から導いた鍵は署名だけに使い、取引の送信は財布が行う。
   サーバ不要。いちばん素直である。
2. **笛の口座に直接テスト用トークンを入れておく**。財布すら不要になり、「笛が財布そのもの」
   という筋が最も鮮明になる。蛇口（faucet）から入れておく運用。

段階0のデモは2、段階1以降は1が向いている。

---

## 5. UX の検討

### 段階0（笛が財布）

1. ページを開く。「笛を吹いて口座を開く」とだけ書いてある。
2. 笛を吹く（既存の復号ページと同じ操作）。
3. 復元できると、**口座のアドレスと残高**が出る。秘密鍵は画面に出さない。
4. 送金の画面。宛先と金額を入れて「吹いた鍵で署名して送る」。
5. 取引が通ったら、その番号（ハッシュ）と、台帳での確認先へのリンクを出す。

要点は、**財布の接続や鍵の管理を利用者に見せないこと**である。笛を吹くという物理の動作が、
そのまま口座を開く動作になっている状態を目指す。

### 段階1（2枚そろって開く金庫）

1. 「1枚目を吹く」→ 記号が読める。
2. 「2枚目を吹く」→ その場で合成し、鍵ができる。
3. 画面に**何に署名するのか**（金庫の住所、受取人＝自分の財布、期限）が日本語で出る。
4. 「開ける」を押すと、財布が手数料を払って取引を送る。
5. 金庫が開き、**開封の記録が台帳に残る**。「2026年7月29日、この2枚がそろって開かれた」と
   誰でも確認できる。

ここでの体験の核心は、**2枚がそろうまで画面が何も教えない**ことである。1枚目を吹いた時点では
「読み取った」としか出さず、秘密の値も残高も見せない。物の性質（片方だけでは何も分からない）
を画面の挙動でも守る。

### 失敗したときの案内

* 1本鳴らなかった → 「もう一度吹いてください」。誤り訂正の余裕を数字で出す。
* 秘密が違う → 「この笛では開きません」。何ビット違うといった手掛かりは出さない。
* 手数料が足りない → 蛇口への案内を出す。

---

## 6. 最小の実装計画

1. **段階0の口座デモ**（契約なし・半日）
   `docs/dapp/index.html` に、笛→鍵導出→アドレス表示→残高照会まで。viem を CDN ではなく
   同梱（Subresource Integrity か自前ビルド）。送金は次段で足す。
2. **鍵導出の仕様確定とテスト**（Node のテストで決定性を固定する）
   同じ秘密から常に同じアドレスが出ること、版を変えると別の口座になることを検査する。
3. **段階1の金庫契約**（Foundry・1日）
   `FluteVault.sol`：登録アドレス、EIP-712 の Claim 検証、nonce、deadline、開封イベント。
   `forge test` で、横取り（claimer が違う署名）と再利用（同じ nonce）が弾かれることを検査。
4. **Amoy へデプロイし、実際に笛で開ける**
5. 段階2（時限・相続）は、必要になってから。

---

## 7. 未解決の論点

* カード（20.8 bit）を実用として扱うなら、合言葉との2要素にするかどうか。UXは重くなる。
* 笛の口座に価値を置く場合、**誰かが総当たりで先に取る**危険を、どう利用者へ説明するか。
* 128 bit のスプールは吹くのに49本かかる。実用の速度として許容できるか（実測で確かめる）。
* 本番チェーンへ移すか、テストネットに留めるか。論文の主張としてはテストネットで十分である。

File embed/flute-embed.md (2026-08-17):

---
name: flute-embed
description: >-
  STLや3mfで与えられた日用品のモデル（ホスト）へ、CipherFluteの笛を鳴る状態のまま
  埋め込むための手順書である。笛が鳴るのは、ボア（共鳴する気柱）・吹き込み口（風道）・
  窓（音の出る切り欠き）の3つの空洞が空のまま保たれ、窓と吸込口が外気に開いているときだけである。
  核心は、ホストに笛を重ねるのではなく、笛の外形の凸包でホストにポケットを彫り抜いてから
  笛を戻すことにある。そうしなければホストの材料がボアを埋めて鳴らない。
  埋め込んだあとは、ボアが中空であることと開口が外気に触れていることを、数値と断面の
  両方で必ず確かめる。
---

# 日用品のモデルに笛を鳴るまま埋め込む

このファイルは、大規模言語モデルの助手に読ませることを想定した作業手順書である。
人が読む導入は `HOWTO.md` にある。まずそちらを読み、細かい判断が要る場面でこちらへ戻るとよい。

## 何が要るか

- Python 3。`trimesh` と `manifold3d` を入れておく。断面を描くなら `matplotlib`、
  水密でないホストを扱うなら `open3d` または `scikit-image` も要る。
- このディレクトリの `embed_flutes.py`（`carve_and_place` / `bore_hollow` /
  `opening_is_air` / `export_multiobj` / `material_depth` と、向きの行列
  `M_WINDOW_PLUS_X` / `M_WINDOW_MINUS_X`）。
- `mini10.py`（笛を作る）と `mini10/recorder-mini-c-v3-half-2-v2.stl`（笛の素の形）。
  この2つがそろって初めて笛を作れる。較正は `../flutes/calibration.json` から読む。
- 音の並びを決めるなら `../codec/cipher_codec.py`。

## 笛の座標系

素の向きは、窓が +z に開き、床が z=0、吸込口が x=0 の端面にあり、長さが +x へ伸びる。
最小の角が原点に来る。以下ではこれを「素の向き」と呼ぶ。

## 塞いではいけない3つの空間

| | 何か | どこに開くか |
|---|---|---|
| ボア | 共鳴する気柱 | 笛の内部（床の上） |
| 吸込口 | 息を入れる口 | 端面（x=0） |
| 窓 | 音が出る切り欠き | 上面（+z） |

ホストと合体させるとき、この3つを埋めてはならない。加えて次の2つを守る。

1. 吸込口と窓がホストに埋没せず、外面に露出すること。
2. 窓の正面に障害物を置かないこと。ハニカムなどの構造があるなら、窓はその反対側へ向ける。

## 手順

1. **ホストを読み込んで調べる。** `trimesh.load` で読み、Sceneなら対象の本体を選ぶ。
   どの面が外から見える面か、板や壁の厚みはいくらか、中実か肉抜きかを調べる。
   厚みは `material_depth(host, 外面の点, 内向きのベクトル)` で測る。0なら肉抜きか開口である。
   肉抜きのホストでは、笛は開口部で「面一に沈んだリブ」になり、材料に触れるところだけで融合する。
   造形にサポートが要ることがある。

2. **笛を作る。** `mini10.flute(L)` は外形の長さがそのまま音になる。
   `mini10.uniform_flute(L, L_max)` は外形を最長管に揃え、内部の仕切り壁でボアの長さを決める。
   **秘密を隠す用途では必ず後者を使う。** 前者は長さを測れば音が読めてしまう。
   外形の長さは `mini10.uniform_body_length()` で求める。最長管ちょうどにすると、
   いちばん低い音だけ閉じた端の壁のぶんボアが短くなり、実測で約1.6mm短く、半音の半分ほど高くずれる。

3. **向きを決める。** 窓と吸込口が空気に開く向きへ回す（行列式が +1 の回転行列を使う）。
   外面が空気なら窓を外面へ、外面に障害物があるなら窓を内面へ向ける。
   吸込口は、口を当てて吹ける外縁や外面に届かせる。

4. **位置を決める。** 面一に沈める（床または窓の面をホストの外面に合わせる）。
   円周上に並べるなら、軸まわりに 360÷本数 度ずつ回す。

5. **彫り抜いて戻す。** `carve_and_place(host, placed_flutes)` を呼ぶ。
   各笛の凸包でホストからポケットを彫り、そこへ笛を戻す。これでボアが埋まらない。
   笛のメッシュそのもので引いてはならない。ボアの領域にホストの材料が残る。

6. **書き出す。** `export_multiobj(host, placed_flutes, out)` で、ホストと笛を別々の
   オブジェクトとして書き出す。ホストを粗い層で速く、笛を細かい層で刷り分けられる。

## 実際に踏んだ失敗

- **ホストに重ねて結合しただけ。** ホストの材料がボアと窓と風道を埋め、鳴らない。凸包で彫り抜く。
- **窓の正面が塞がっていた。** 窓を外面へ向けたが、その外面にハニカムがあった。窓を内面へ反転する。
- **窓と空洞のあいだに薄い材料が残った。** 窓の面を空洞の壁のちょうど外側に合わせると、
  0.5mmほどの殻が残って密閉される。彫り抜きは凸包のぶんしか行わないので、この殻は自動では消えない。
  笛の背中（窓の反対側）を壁に合わせ、本体を空洞へ食い込ませる。
- **面一に置くと彫り抜きが不安定になる。** 凸包の面とホストの面が同一平面になるためで、
  彫り残しが出る（36本のうち23本のボアに材料が残ったことがある）。
  彫る道具のほうを、外へ抜ける向き（吸込口の向きと窓の向き）へ0.4〜0.6mm広げた凸包にする。
  笛そのものは動かさない。余分に彫れるのは表面のごく薄い層だけである。
- **吸込口や窓をホストの面よりわずかでも内側に置いた。** その厚みぶんの材料が被って塞がる。
  面一（0.0mm）でよい。窓だけは面一だと薄皮が残ることがあるので、0.3mmほど出しておくと確実である。
- **窓の向きを、検査が返した角度の値から組み立て直した。** 符号を取り違えて材料の側を測り、
  鳴る設計を「塞がっている」と誤って判定した。**窓の向きは角度からではなく、配置に使った
  回転行列から取る。** `R_world = 印刷姿勢の回転 @ 配置の回転` に素の向きの窓ベクトル (0,0,1) を掛ける。

## 印刷の向き

**笛はどの向きに寝かせるかで鳴るかどうかが決まる。** 実機で角度を掃引して確かめた範囲は次のとおりである。

- **横置き（長軸が水平）で、窓が真上を0度として長軸まわりに −135度から +135度なら鳴る。**
  360度のうち270度が使える。音のずれは0度の対照に対して2.4セント以内であった。
- **180度（窓が真下）は鳴らない。** 管の天井が正しく被覆されず、窓の造形も崩れる。
- **縦置きで吸込口が上は鳴らない。** 吸込口から窓への風道（高さ1.0mmの垂直な細い管）が埋まる。
- 縦置きで吸込口が下は鳴るが、低い音は狙いより約95セント高くずれ、高い音では一回の吹鳴で
  複数の基音が同時に現れる。復号に使うなら1本ずつ実機で確かめること。

**この範囲は0.08mmの層で刷ったときのものである。** 0.2mmで刷ると狭くなり、窓が真上（0度）の
ときだけ鳴らないことがある。窓の天井が橋渡しになり、層が厚いと垂れるためである。
粗い層で刷るなら窓は横向きにする。

配置したら `orient_check.py` で確かめる。

```python
from orient_check import check_orientation, check_many, report, check_mesh_tilt
r = check_orientation(R)                                             # 笛に掛けた回転行列
report(check_many([(name, dict(R=R)) for name, R in placements]))    # まとめて
```

すでに書き出した3mfを後から調べるときは `check_mesh_tilt(mesh)` を使う。
メッシュから確実に取れるのは長軸の傾きだけだが、いちばん危ない「縦置きになっている」は捕まえられる。

## 検証（数値と断面の両方を必ず行う）

- **ボアが中空か。** `bore_hollow(result, 点列)` で、床の少し上とボアの領域の点が
  結果の外にある（＝中空である）ことを確かめる。すべて真になること。
- **開口が外気に触れているか。** `opening_is_air(result, 点)` を、窓のすぐ外側と
  吸込口のすぐ外側について確かめる。
- **被りは0.02mm刻みで探す。** 1mm刻みでは0.35mmの薄い被りを見落とす。
  外へ向かって細かく点を並べ、ホストの中に入る最大の深さを出す。0.00mmでなければ塞がっている。
- **ホストと笛を結合したメッシュに contains をかけてはならない。** 殻が触れ合うと内外の判定が
  壊れ、埋まっていないボアを「埋まっている」と誤って判定する。判定はオブジェクトごとに行う。
- **窓の前が空気かどうかは、実際のgcodeでも確かめる。** モデルの上では空気でも、
  スライサが薄い殻を刷ることがある。窓の外側1〜4mmに点を並べ、`check_cavity.py` の
  `dist_to_segments` で押し出し線までの距離を測る。0.4mm以上あれば開いている。
  窓は吸込口から12〜16.5mmのところにある。
- **吸込口がどちら側かを取り違えない。** 素の向きでは吸込口が x=0 で長さが +x である。
  配置と印刷姿勢の回転を経ると、造形機の座標では吸込口が最小の側に来ることがある。
  端を間違えると、音に関係しない密閉された空洞（仕切り壁より先）を測ってしまう。
- **断面を目で見る。** 笛を長手と横に切る平面で切り、D字の断面が殻になっていること、
  窓が外へ開いていること、吸込口が外縁に開いていることを確かめる。
  断面を平面座標へ落とすと座標系がずれるので、世界座標のまま描く。

## ホストの形ごとの置き方

- **円盤の外周（放射状に寝かせる）。** 円周を本数で割り、笛を寝かせて放射状に置く。
  窓は内側へ、吸込口は円周に接するように置く。
- **薄い板や壁（鉛直に立てる）。** 厚さ2mm程度の板で連続した平面が取れない場合は、笛を立てる。
  管の長さの方向を鉛直にし、吸込口を板の上端に面一で露出させ、窓を側面の外向きに開く。
  笛の全長を板に食い込ませて凸包で彫る。内側と外側のすべての壁へ一定の間隔で分散させる。
- **円筒の穴（穴の壁へ寄せる）。** 穴の中心と径は、点が内部にあるかどうかを格子で調べて実測する。
  断面を平面へ落とす方法は座標がずれるので使わない。穴の四方に最大4本を十字に置ける。
  笛どうしの干渉は、凸包ではなく実際のメッシュどうしの重なりの体積で確かめる。

## 水密でないホスト

厳密な立体を要求する演算は、ホストが水密でないと失敗する。穴を埋めるか、格子で作り直す。

```python
vg = host.voxelized(pitch).fill()
m = vg.marching_cubes
m.apply_transform(vg.transform)      # 格子の番号を実寸へ戻す。忘れると寸法が壊れる
```

## 刷るときの注意

- **複数のオブジェクトからなる3mfを、スライサに自動整列させてはならない。**
  各オブジェクトが個別に並べ直され、笛がホストから離れる。整列を切るか、1つのメッシュに結合する。
- **笛が多いときは、笛をすべて1つのメッシュに結合するとよい。** ホスト本体と笛まるごとの
  2オブジェクトになり、オブジェクトごとの設定が2回で済む。物理的に離れていても1つとして扱える。
- **笛だけ別の設定にしたいときは、1つのオブジェクトの中の2つの部品にする。**
  オブジェクトを分けると、床に接していない笛の側が「浮いている」と判定されて刷れないことがある。
- 別の設定にこだわらないなら、ホストの充填を0にして中空で刷ると軽く速い。笛は壁2周で鳴る。
- **層の高さの設定が黙って無視されることがある。** 継承をたどらないスライサでは、
  0.08mmを指定したつもりが既定の0.2mmに落ちる。投入する前に、生成されたgcodeの層の高さと
  総層数を必ず確かめる。

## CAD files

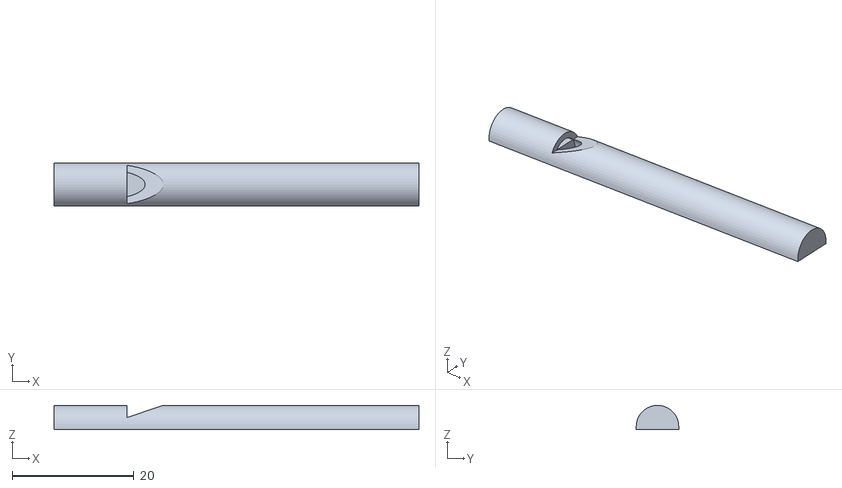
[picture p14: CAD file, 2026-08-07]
embed/mini10/recorder-mini-c-v3-half-2-v2.stl
60.0 x 7.00 x 4.00

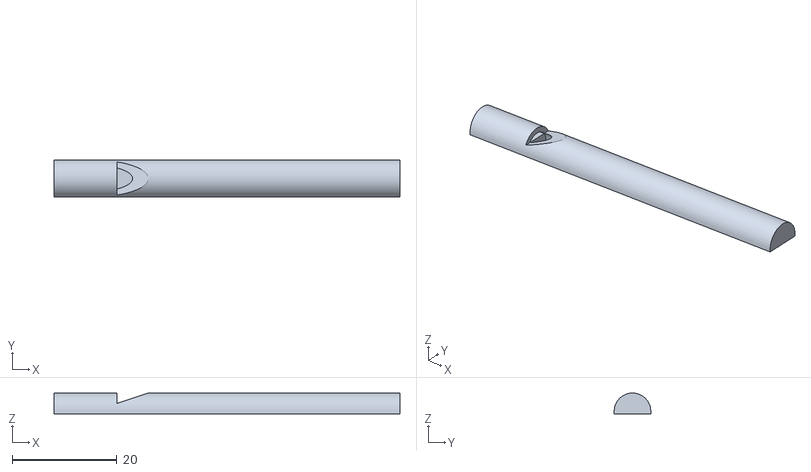
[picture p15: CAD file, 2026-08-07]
flutes/uniform/flute_A6.stl
66.0 x 7.00 x 4.00

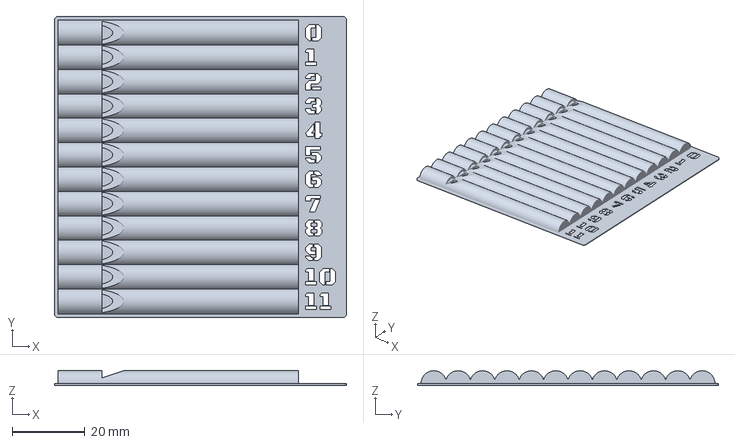
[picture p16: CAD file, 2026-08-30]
gallery/models/matching.3mf
80.2 x 82.7 x 4.00 mm

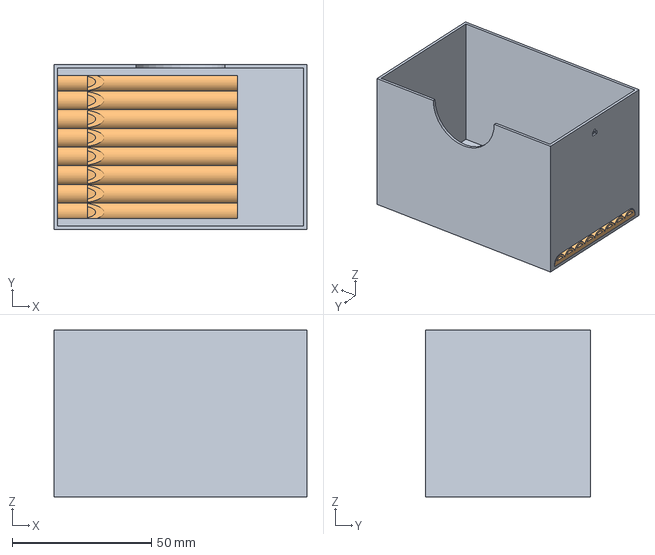
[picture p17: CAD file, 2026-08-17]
gallery/models/box.3mf
91.0 x 59.4 x 60.0 mm
cardbox_0.28fast
flutes_0.08careful

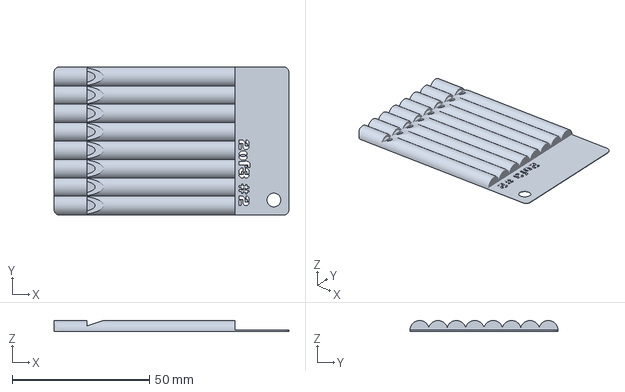
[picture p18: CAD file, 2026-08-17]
gallery/models/card.3mf
85.6 x 54.0 x 4.00 mm

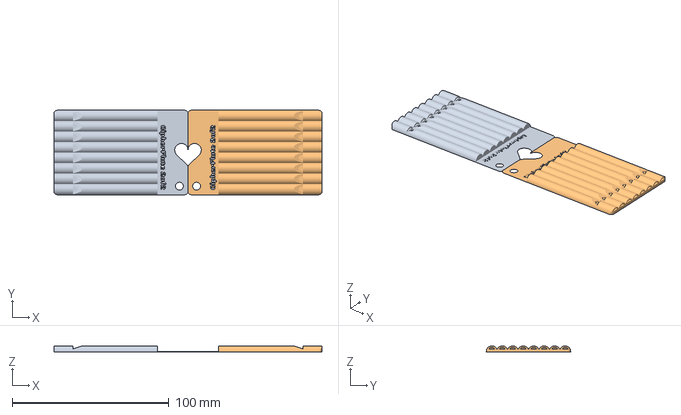
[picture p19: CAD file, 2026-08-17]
gallery/models/paircards_2of2.3mf
171.2 x 54.0 x 4.00 mm
cardA_0.08careful
cardB_0.08careful

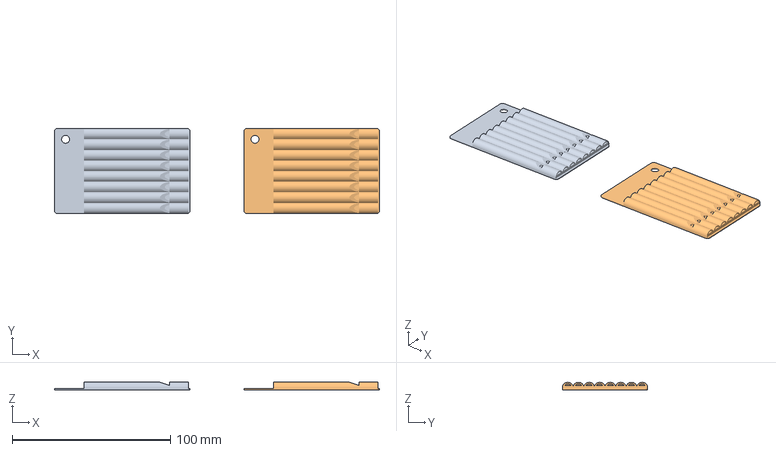
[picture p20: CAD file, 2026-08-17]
gallery/models/karuta_2of2.3mf
205.2 x 54.0 x 4.75 mm
sutoku_edge_upper
sutoku_edge_lower

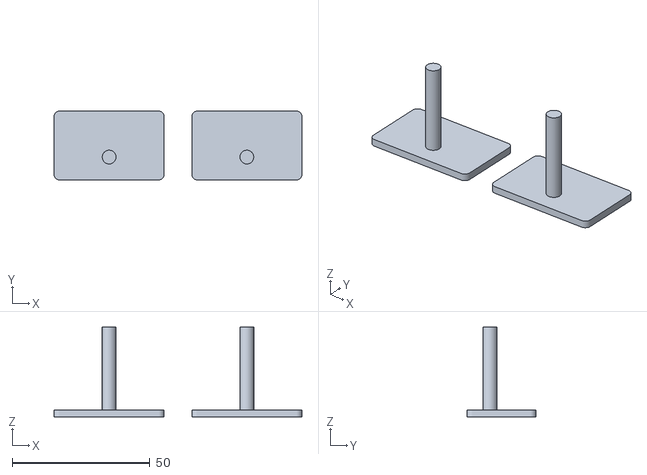
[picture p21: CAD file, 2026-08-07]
gallery/models/frame_stand.stl
90.0 x 25.0 x 32.5

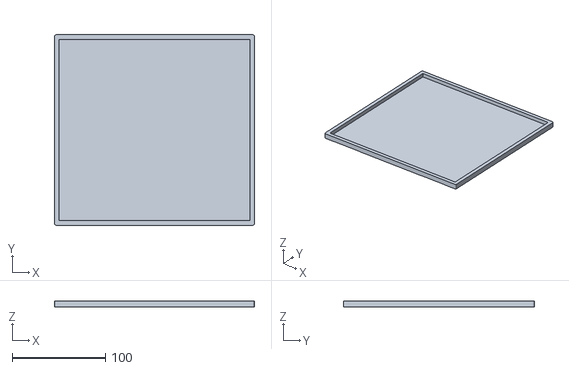
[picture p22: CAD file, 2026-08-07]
gallery/models/frame_box.stl
214.5 x 204.4 x 6.68

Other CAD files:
flutes/uniform/flute_As6.stl
flutes/uniform/flute_C7.stl
flutes/uniform/flute_B6.stl
flutes/uniform/flute_Ds7.stl
flutes/uniform/flute_Cs7.stl
flutes/uniform/flute_D7.stl
flutes/uniform/flute_F7.stl
flutes/uniform/flute_Fs7.stl
flutes/uniform/flute_Gs6.stl
flutes/uniform/flute_E7.stl
flutes/uniform/flute_G7.stl

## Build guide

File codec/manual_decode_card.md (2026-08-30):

# 手で復号するための早見表　CipherFlute / GF(11)

**この1枚があれば、計算機なしで誤り訂正まで行える。** 使うのは足し算と引き算だけである。
掛け算と割り算は、下の対数表を使って足し算と引き算に置き換える。

---

## 表A　音名とスロット番号

| 音名 | G#6 | A6 | A#6 | B6 | C7 | C#7 | D7 | D#7 | E7 | F7 | F#7 | G7 |
|---|---|---|---|---|---|---|---|---|---|---|---|---|
| スロット | 0 | 1 | 2 | 3 | 4 | 5 | 6 | 7 | 8 | 9 | 10 | 11 |

基準笛は C7（スロット4）である。照合笛（12本を1枚の板に並べたもの）には、このスロット番号がそのまま刻んである。

**スロット番号と記号は別のものである。混同しないこと。**

| | 範囲 | 個数 | 何を指すか |
|---|---|---|---|
| スロット番号 | 0〜11 | 12 | 音の置き場。表Aの下の段。照合笛に刻んである数 |
| 記号 | 0〜10 | 11 | 位数11の有限体の要素。手順1で変換して得る数 |

隣り合う笛が同じ音にならない決まりのため、12個の置き場で記録できる値は11通りになる。
**書き取るときは必ず区切りを入れる。** 「10」を「1」と「0」の2つと読むと記号が1つ増え、
これは位置の誤りではないのでパリティでは直せない。

## 表B　べき乗表（2の累乗、mod 11）

| k | 0 | 1 | 2 | 3 | 4 | 5 | 6 | 7 | 8 | 9 |
|---|---|---|---|---|---|---|---|---|---|---|
| **2^k** | 1 | 2 | 4 | 8 | 5 | 10 | 9 | 7 | 3 | 6 |

## 表C　対数表（2を底とする、mod 11）

| x | 1 | 2 | 3 | 4 | 5 | 6 | 7 | 8 | 9 | 10 |
|---|---|---|---|---|---|---|---|---|---|---|
| **log x** | 0 | 1 | 8 | 2 | 4 | 9 | 7 | 3 | 6 | 5 |

**掛け算は log を足し、割り算は log を引く。どちらも mod 10 で行う。**
結果を表Bで引き戻せば答えになる。0 は対数を持たないので、別に扱う。

---

## 手順1　音を記号に直す

1. 笛を順に吹き、鍵盤楽器か照合笛で**同じ高さの音**を探す。表Aでスロット番号を読む（照合笛なら、その笛に刻んである数がそのままスロット番号である）。
2. 先頭は基準笛である。以降の笛について、**記号 = （今回のスロット − 前回のスロット − 1） mod 12** を計算する。引き算が負になったら12を足してから1を引けばよい。結果は必ず0から10になる（隣り合う笛は同じ音にならないため）。

これで記号の列（0から10までの数）が得られる。パリティを付けていない用途では、**この列がそのまま秘密である。以降は不要である。**

## 手順2　シンドロームを求める

記号の列を $v_0, v_1, \dots, v_{n-1}$ とする（末尾の2つがパリティ）。

$$S_1 = \sum_i v_i \cdot 2^{(n-1-i)}, \qquad S_2 = \sum_i v_i \cdot 2^{2(n-1-i)} \pmod{11}$$

**紙の上での計算。** 位置 $i$ の重みの log は、$S_1$ では $(n-1-i) \bmod 10$、$S_2$ では $2(n-1-i) \bmod 10$ である。
各項について「表Cで $v_i$ の log を引き、重みの log を足し、mod 10 にして、表Bで戻す」。全部を足して mod 11 を取る。

**$S_1 = S_2 = 0$ なら誤りはない。手順4へ進む。**

## 手順3　誤りを1つ直す

$$\text{位置の指数} = (\log S_2 - \log S_1) \bmod 10, \qquad j = (n - 1 - \text{位置の指数}) \bmod 10$$

$$\log e = (2 \log S_1 - \log S_2) \bmod 10 \quad \Rightarrow \quad e = 2^{\log e}\ (\text{表B})$$

**$j$ 番目の記号から $e$ を引き、mod 11 を取る。** これで直る。

鳴らなかった笛が分かっている場合（消失が1つ）は、その位置を $j$ として $e$ だけを求めればよい。
$e = S_1 / 2^{(n-1-j)}$ なので、$\log e = (\log S_1 - (n-1-j)) \bmod 10$ である。

## 手順4　記号を秘密に戻す

パリティの2記号を落とし、残りをそのまま読む。

---

## 例（実際に検算したもの）

データ 3, 7, 0, 10, 4 に対する符号語は **3, 7, 0, 10, 4, 10, 7**（末尾2つがパリティ）である。

3番目（位置2）を 0 と読むべきところ **6** と読み違えたとする。

1. シンドロームは $S_1 = 8$, $S_2 = 7$
2. $\log 7 - \log 8 = 7 - 3 = 4$ 　→ 　位置の指数 4 　→ 　$j = 6 - 4 = 2$
3. $2 \log 8 - \log 7 = 6 - 7 = -1 \equiv 9$ 　→ 　$e = 2^9 = 6$（表B）
4. 位置2の値 $6 - 6 = 0$ 　→ 　**復元できた**

**引き算2回と表引き2回で終わる。**

---

## 検証

`scripts/verify_manual_decode.py` が、この手順を実装の復号器と突き合わせる。
データ2記号から8記号まで、位置と誤差を変えた300通りで一致を確認した。

## 適用範囲

パリティ2記号で直せるのは、**誤り1つ、または消失2つ**までである。
消失1つと誤り1つが重なると（$2 \times 1 + 1 = 3 > 2$）直せない。
それ以上を人手で扱うには、パリティを増やして連立方程式を解くことになる。

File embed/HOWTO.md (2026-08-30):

# 日用品に笛を埋め込む

任意の3Dモデル（**ホスト**と呼ぶ）に、鳴る状態のまま笛を埋め込む手順である。

開発用の作業手順書を、外部の人が読める形に書き直したものである。実行環境への依存を外し、
手元の環境に固有の話（プリンタの機種、社内の置き場）を落としてある。

## 鳴るために塞いではいけない3つの空間

笛が鳴るのは、次の3つが空のまま保たれ、かつ外気に通じているときだけである。

| | 何か | どこに開くか |
|---|---|---|
| **ボア** | 共鳴する気柱 | 笛の内部（床の上） |
| **吸込口** | 息を入れる口 | 端面（長さ方向の始点） |
| **窓** | 音が出る切り欠き | 上面 |

ホストと合体させるとき、この3つを埋めてはならない。**見た目が正しくても、
ここが埋まっていれば音は出ない。**

## 核心：先に彫り抜いてから戻す

笛をホストに重ねるだけでは鳴らない。ホストの材料が笛の空洞へ入り込むためである。

**笛の外形の凸包でホストにポケットを彫り抜き、そのあとで笛を戻す。**

```python
import embed_flutes as EF

pocket = EF.carve_and_place(host_mesh, flute_mesh, transform)
```

凸包を使うのは、笛の外形そのものだと窓や吸込口の切り欠きにホストの材料が残るためである。
凸包なら切り欠きも含めて余さず彫れる。

## 向き

**印刷して鳴る向きには範囲がある。** 横置きで、窓の向きが −135度から +135度の間なら鳴る
（360度のうち270度）。真下（180度）と、縦置きで吸込口が上を向く置き方は鳴らない。

```bash
python3 orient_check.py --angle 45      # ok / ng を返す
```

**窓が真上（0度）を向く置き方を勧める。** 壁の縁に垂直に立てる置き方は造形不良が多い。

窓と吸込口は、空気に開いた方向へ向けること。ハニカム構造などの障害物の正面に窓を置かない。

## 埋め込んだあとの検査

**印刷する前に、2つの検査で確認する。** これで鳴らない物を作ってしまう失敗はほとんど防げる。

### 1. 向きの検査

```bash
python3 orient_check.py --stl embedded.stl
```

### 2. 空洞の検査（スライスした後）

スライスして出来た実際の経路を読み、笛の空洞に材料が置かれていないかを調べる。

```bash
python3 check_cavity.py --design embedded.3mf --print sliced.gcode.3mf
```

考え方は「**笛の凸包の中にありながら、笛の実体の外にある空間**が空気の通り道である」
というものである。押出の線分を細かい点に分け、凸包に入る点だけを取り出して、
笛の実体からどれだけ離れているかを測る。

ボアは吸込口と窓で外気につながっているので「閉じた殻」としては現れない。
**殻を数える検査では見つけられない**ので、この向きで調べる必要がある。

**素地と笛が一体になっている物には使えない**（笛の形状を名前で照合するため）。
その場合は、材料の量を同じ作りの物と比べるとよい。ボアが埋まっていれば大きく増える。

## 笛の選び方

`../flutes/uniform/` の統一管長の笛を使う。**外形はすべて同じで、中の空洞の長さだけが違う。**
見ただけではどの音か分からないので、秘密を記録するときはこちらを使う。

外形の長さがそのまま音になる版（可視長）もあるが、長さから音が読めてしまうので、
秘匿が要るときには向かない。確実に鳴らせることだけを優先するなら選択肢になる。

## よくある失敗

| 症状 | 原因 |
|---|---|
| 見た目は正しいのに鳴らない | ポケットを彫らずに重ねた。ホストの材料がボアに入っている |
| 一部の笛だけ鳴らない | その笛の向きが範囲の外にある。`orient_check.py` で確認する |
| 窓の側から音が出ない | 窓の正面に障害物がある。空気に開いた方向へ向ける |
| 材料が想定の倍になる | スライス済みのファイルを再スライスした。ボアが中実になる |

## 最小の例

`examples/` に、箱に笛を4本埋め込む例がある。

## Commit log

2026-08-07 CipherFlute の公開用リポジトリを起こした
    論文（WISS2026 投稿中）の成果物を、開発用リポジトリ ai-fue から切り出した。
    切り出しは手作業の複製ではなく ai-fue の scripts/export_public.py で行うので、
    更新のたびに同じ手順で作り直せる。
    flutes/ 統一管長の笛12音ぶんのSTLと較正データ
    codec/ 符号の参照実装（Python）と試験ベクタと仕様書
    decoder/ ブラウザだけで動く復号器。検査94件つき
    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
    [flute_A6.stl, flute_As6.stl, flute_B6.stl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]
2026-08-07 用いた画像もパブリックドメインである旨を NOTICE に明記した
2026-08-17 早見表・埋め込みの手順書・作例4件を足し、参照実装が動かない不具合を直した
    ★動かなかったもの★ codec/cipher_codec.py が、同梱していない notes.py を
    読んでいて起動しなかった。embed/check_cavity.py も同じで、開発リポジトリの
    構成を前提にしていた。両方とも公開版だけで動くようにした。
    ★足したもの★
    - 紙の上で誤り訂正まで行うための早見表(codec/manual_decode_card.md)と、
    手順が実装と食い違っていないかを確かめる道具
    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
    [box.3mf, card.3mf, karuta_2of2.3mf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]
2026-08-17 暗号笛ウォレットを同梱した（テストネットの実験）
    論文が「実装した」と書いているものが、この成果物に入っていなかった。
    笛から鍵と口座を導き、残高を見て送金までできるページである。財布アプリは
    介さず、笛から導いた鍵が直接署名する。検査38件（鍵導出9件・送金29件）。
    ★本物の資産には使わないこと★ という但し書きと、その理由（カード1枚の20.8bitでは
    アドレスが台帳に現れた時点で総当たりされる。遅い鍵導出は費用を上げるだけで
    情報量を補わない）を README に明記した。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
2026-08-18 ウォレットと復号器を開発側の最新へ揃えた
    ★ウォレット★ 読む笛の設定をURLで指定する形（lo・hi・parity・mode・norepeat・cards・
    expect・shares・name・label）。k-of-n は担体の番号を総当たりし、残高が入っている口座を
    採るので、どれを吹いたか覚えていなくてよい。合言葉つきの送金、音高メーター表示
    （meter=1）、実演の録画を音源にする入口（demoaudio=）も入った。
    _u64.js は u64.js に改名した。GitHub Pages がアンダースコアで始まるファイルを配信せず、
    ページ全体が動かなくなるためである。読み込みには版（?v=2）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
2026-08-24 復号ページとウォレットのサイト一式をdocs/へ収録した（GitHub Pages配信用）
    これまで ai-fue リポジトリのPagesでデバッグ配信していたものを移設した。
    decoder/ はコードの公開版、docs/ は動くサイトという役割分担である。
2026-08-29 READMEを整理し、引用形式をリポジトリの引用に改めた
2026-08-29 作例の写真をREADMEとギャラリーに埋め込み、スプール・本立て・照合笛の写真を追加した
2026-08-30 早見表の音→記号の変換式を mod 12 に修正した（実装と一致させた）
    引き算が負になる巻き戻りの場合に mod 11 では答えがずれる。負のときの
    手当て（12を足す）と、結果が必ず0〜10になる理由も書き足した。
2026-08-30 照合笛の造形データを収録し、文書全体の文体を論文の規範に合わせて整えた
    照合笛（gallery/models/matching.3mf・12スロット・秘密なし）は読み出しの要なのに
    写真のみだったので、実際に刷った版の造形データを収録し、galleryに節を立てた。
    文体は論文推敲の規範で整えた。「要らない」を「不要である」へ、文末の訓読み単独動詞を
    操作を特定する熟語へ、「木揺すり」の直訳造語を「ツリーシェイキング」へ。警告・限界・
    秘匿性を述べる否定文と、人手復号の早見表の算数の言葉は意図して残した。
    あわせて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
    [matching.3mf]
2026-08-30 文末の「式で結ぶ」を「式で対応づける」に改めた（栗原さん指摘）
2026-08-30 作例の名称変更にメインページとNOTICEを追従させた
    galleryの改名（かるた札ペアキーホルダー・ペアカード・箱）に合わせ、
    メインページの一覧を新名称にし、収録済みの照合笛を書き足した。
    NOTICEの節題も同じ名称にした。
2026-09-05 Zenodo保管と引用のためのメタデータを足した（.zenodo.json・CITATION.cff）
2026-09-05 ZenodoのDOI（10.5281/zenodo.22342650）をREADMEとCITATION.cffに記した
2026-09-11 docs/ を唯一の置き場にし、復号ページを整理した（復号・秘密分散・共通の読み取り部）
    decoder/ と wallet/ の写しを消し、GitHub Pages の配信元 docs/ だけを残した。
    docs/cipher は index.html（担体1つの復号。入口は「続けて吹く」と「一定のテンポで吹いてあとから読む」）、
    share.html（2-of-2 と k-of-n）、reader.js（両ページ共通の読み取り部）になった。
    古い版 index_v11〜v14・動画撮影用の demo.html・Chordika の chordika.html・実演の録音 _demoaudio・
    開発用の測定値検査は公開側から外した（開発用リポジトリにだけ置く）。
    README・NOTIC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
2026-10-28 WISS 2026 の宝探し専用の、いちばん簡単な復号ページ docs/cipher/hunt.html を足した。開いたらすぐにマイクで聞き始め、音の高さが変わったところで1本ずつに区切り、1本入るたびに c= を開ける秘密があるかを試して、開けたら移り先へ進む。終了のボタンも設定のつまみも置かない
2026-10-28 宝探しの復号ページ hunt.html を v2 にした。秘密が開いたときに、金色に光る輪と宝石、「財宝を発見！」の大きな文字、紙吹雪、ド・ミ・ソ・ドの短いファンファーレ、長めの振動で祝い、2.6秒後に財宝のページへ移る。動きを減らす設定の端末では紙吹雪とはねる動きを出さない
2026-10-28 宝探しの復号ページ hunt.html を v2.1 にした：画面の下端に版の番号を出した。番号は VERSION の1か所で決め、タブの題にも同じ値を出す。直すたびに小さい桁を上げる
2026-10-28 宝探しの復号ページ hunt.html を v2.2 にした：「基準の笛から順に吹いてください」を「印のついている笛から順に吹いてください」に直した（基準の笛と言っても伝わらないため）
2026-10-28 宝探しの復号ページ hunt.html を v3.0 にした：財宝の扉を守る精霊（守り人）が魔法の笛の調べを待つ、という見立てに作り替えた。夜空に星が瞬き、古代文字の刻まれた魔法陣が回る。守り人の台詞を大きく出し、していただくことを普通の言葉で下に添える。聞き取った音は音名でなく古代文字で刻む。秘密が開くと、魔法陣が金色に燃え、扉が左右に開いて光があふれ、光の粒が舞い、ハープのような分散和音が鳴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
2026-10-28 宝探しの復号ページ hunt.html を v3.1 にした：トップと「扉の前に立つ」の画面に、守り人の口調の注意書き「魔法の笛の調べは神聖なるもの。他の誰にも聞かれてはならぬ。奏でる前に、周りに誰もいないことを確かめよ。」と、普通の言葉の説明（近くで同じページを開いている人がいると、その人の端末でも扉が開いてしまう）を足した。PC とスマートフォンで同時に開いていて、両方で同時に開いてしまった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
    Co-Authore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
2026-10-28 宝探しの復号ページ hunt.html を v3.2 にした：注意書き（魔法の笛の調べは神聖なるもの……）をページの冒頭から「はじめから奏で直す」のボタンの下へ移した。「扉の前に立つ」の画面でも、ボタンと説明の下へ移した。375×812 と 375×667 の両方で1画面に収まることを確かめた
